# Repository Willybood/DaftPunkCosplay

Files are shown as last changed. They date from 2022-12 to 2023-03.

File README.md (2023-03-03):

# Daft Punk Cosplay
 A Daft Punk Cosplay created for London MCM ComicCon 2023. It consists of a set of LEDs and sound changer embedded into a helmet.
 The LED strip responds to the user talking, and the LED matrix plays animations when buttons embedded in a glove are pushed.
 
 <div align="center">
 
 
 
 
 </div>

 This design also features an 3D printed logo design which is then stitched onto the back and has threaded EL wire contained within.
 
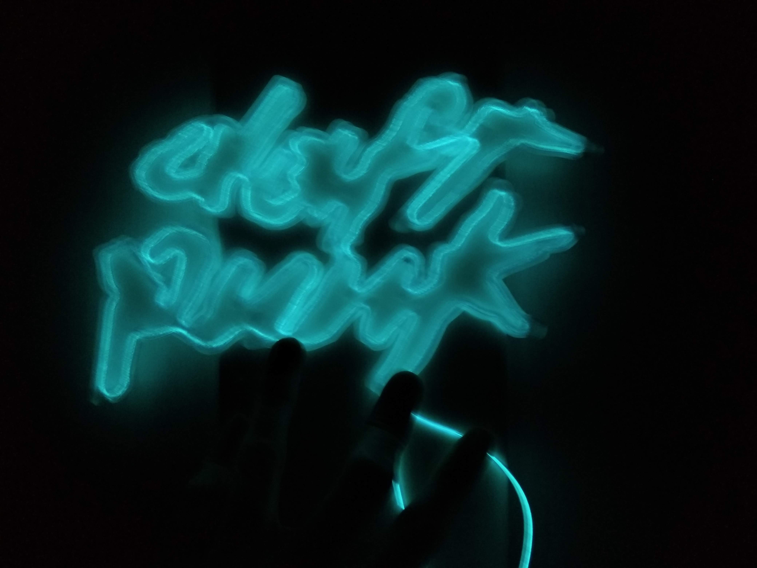
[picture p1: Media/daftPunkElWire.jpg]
 
 
 ## Bill of materials
  - [Raspberry Pi Zero W](https://www.amazon.co.uk/Raspberry-Pi-Zero-Wireless-model/dp/B06XFZC3BX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)
  - [WS2812B 8x8 LED matrix](https://www.amazon.co.uk/AZUOCN-Flexible-Individually-Addressable-Programmable/dp/B09DV8PZY1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)
  - [WS2812B LED strip, cut into 2 7 LED segments](https://www.amazon.co.uk/Individually-Addressable-Programmable-Waterproof-Decoration/dp/B0BLRN29V2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)
  - A USB sound card and adapter for the Pi
  - [A small lapel mic](https://www.amazon.co.uk/AGPTEK-Microphone-Professional-Omnidirectional-Condenser/dp/B07SHSHW6H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)
  - [A powered wired speaker](https://www.amazon.co.uk/dp/B07PDC69KT/ref=twister_B07PJNV454?_encoding=UTF8&psc=1)
  - 5 x little breadboard buttons
  - 2 x solderable breadboards
  - [Sound detector with digital output](https://www.amazon.co.uk/gp/product/B089QHMC8Y/ref=ppx_yo_dt_b_asin_title_o01_s00?ie=UTF8&psc=1)
  - 6 x 1.5 metre wires
  - 9 x 1.0 metre wires
  - 3 x 0.3 metre wires
  - A set of [Dupont cables](https://www.amazon.co.uk/gp/product/B07SYKPB86/ref=ppx_yo_dt_b_search_asin_title?ie=UTF8&psc=1)
  - A set of breadboard jumpers
  - One black suit, shirt, and tie
  - [A spaceman helmet](https://www.amazon.co.uk/gp/product/B01HQTGPIS/ref=ppx_yo_dt_b_search_asin_title?ie=UTF8&psc=1)
  - Modelling cardboard for the glove parts
  - Some black primer, gold, and clear finisher spraypaint to apply to the helmet and glove parts.
  - Natural 3D printer PLA
  - [Neon EL wire](https://www.amazon.co.uk/gp/product/B099FNFCY7/ref=ppx_yo_dt_b_search_asin_title?ie=UTF8&psc=1)
  - Some long thin black gloves
 ## Installation
On the Pi you can install the script by cloning the repository and running the command:
```
sudo python3 ./Install/install.py
```
The construction of the electronics can be seen in the Fritzing diagram:

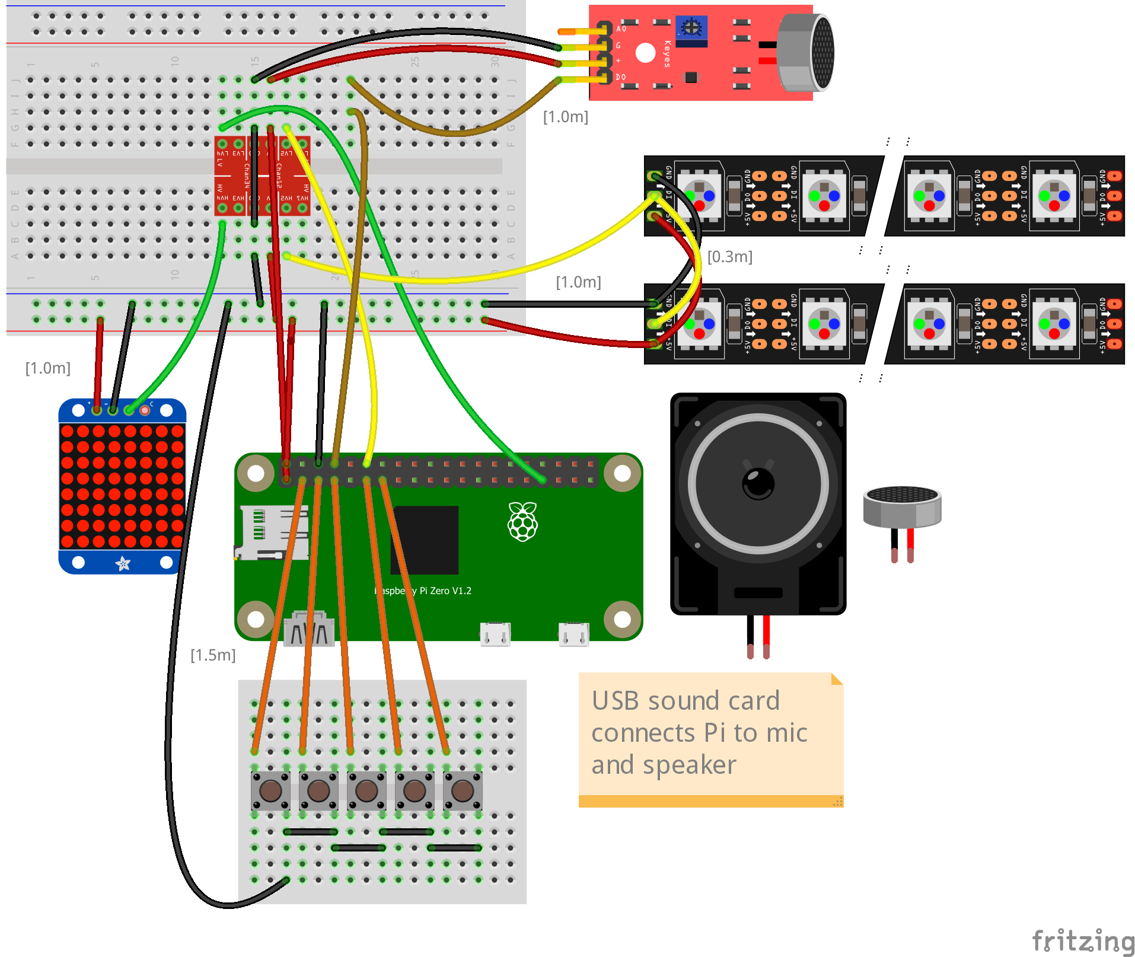
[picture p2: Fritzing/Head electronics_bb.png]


The lapel mic and sound detector were placed on the USB matrix in front of the mouth.
The gloves were made by cutting the modelling cardboard using a laser cutter and [the input SVG file](https://github.com/Willybood/DaftPunkCosplay/blob/main/Laser%20cuts/glove.svg).
The logo on the back was made using [this laser cut design](https://www.thingiverse.com/thing:683140) from Thingiverse (with special thanks to [Andyways](https://www.thingiverse.com/andyways)). It's available in the repo [here](https://github.com/Willybood/DaftPunkCosplay/blob/main/3D%20prints/DaftP_logo_mk1.1.stl) if needed.
## Running
Browse to the repo's folder and run the below command:
```
sudo python3 ./Python/main.py
```

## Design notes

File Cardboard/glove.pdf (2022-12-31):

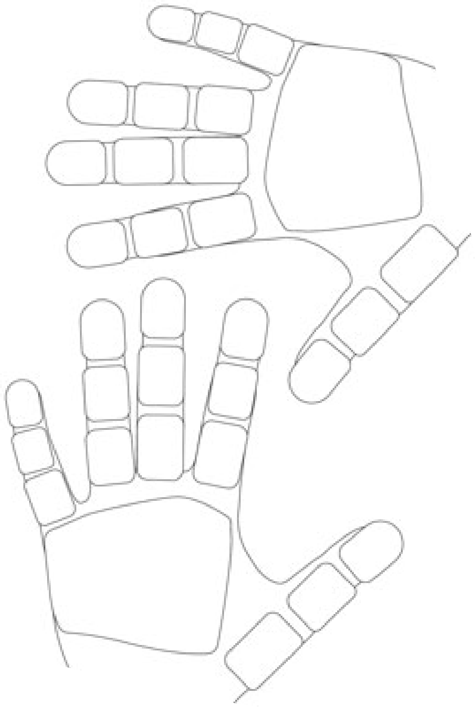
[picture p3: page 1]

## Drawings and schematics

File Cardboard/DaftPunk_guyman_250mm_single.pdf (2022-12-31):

up

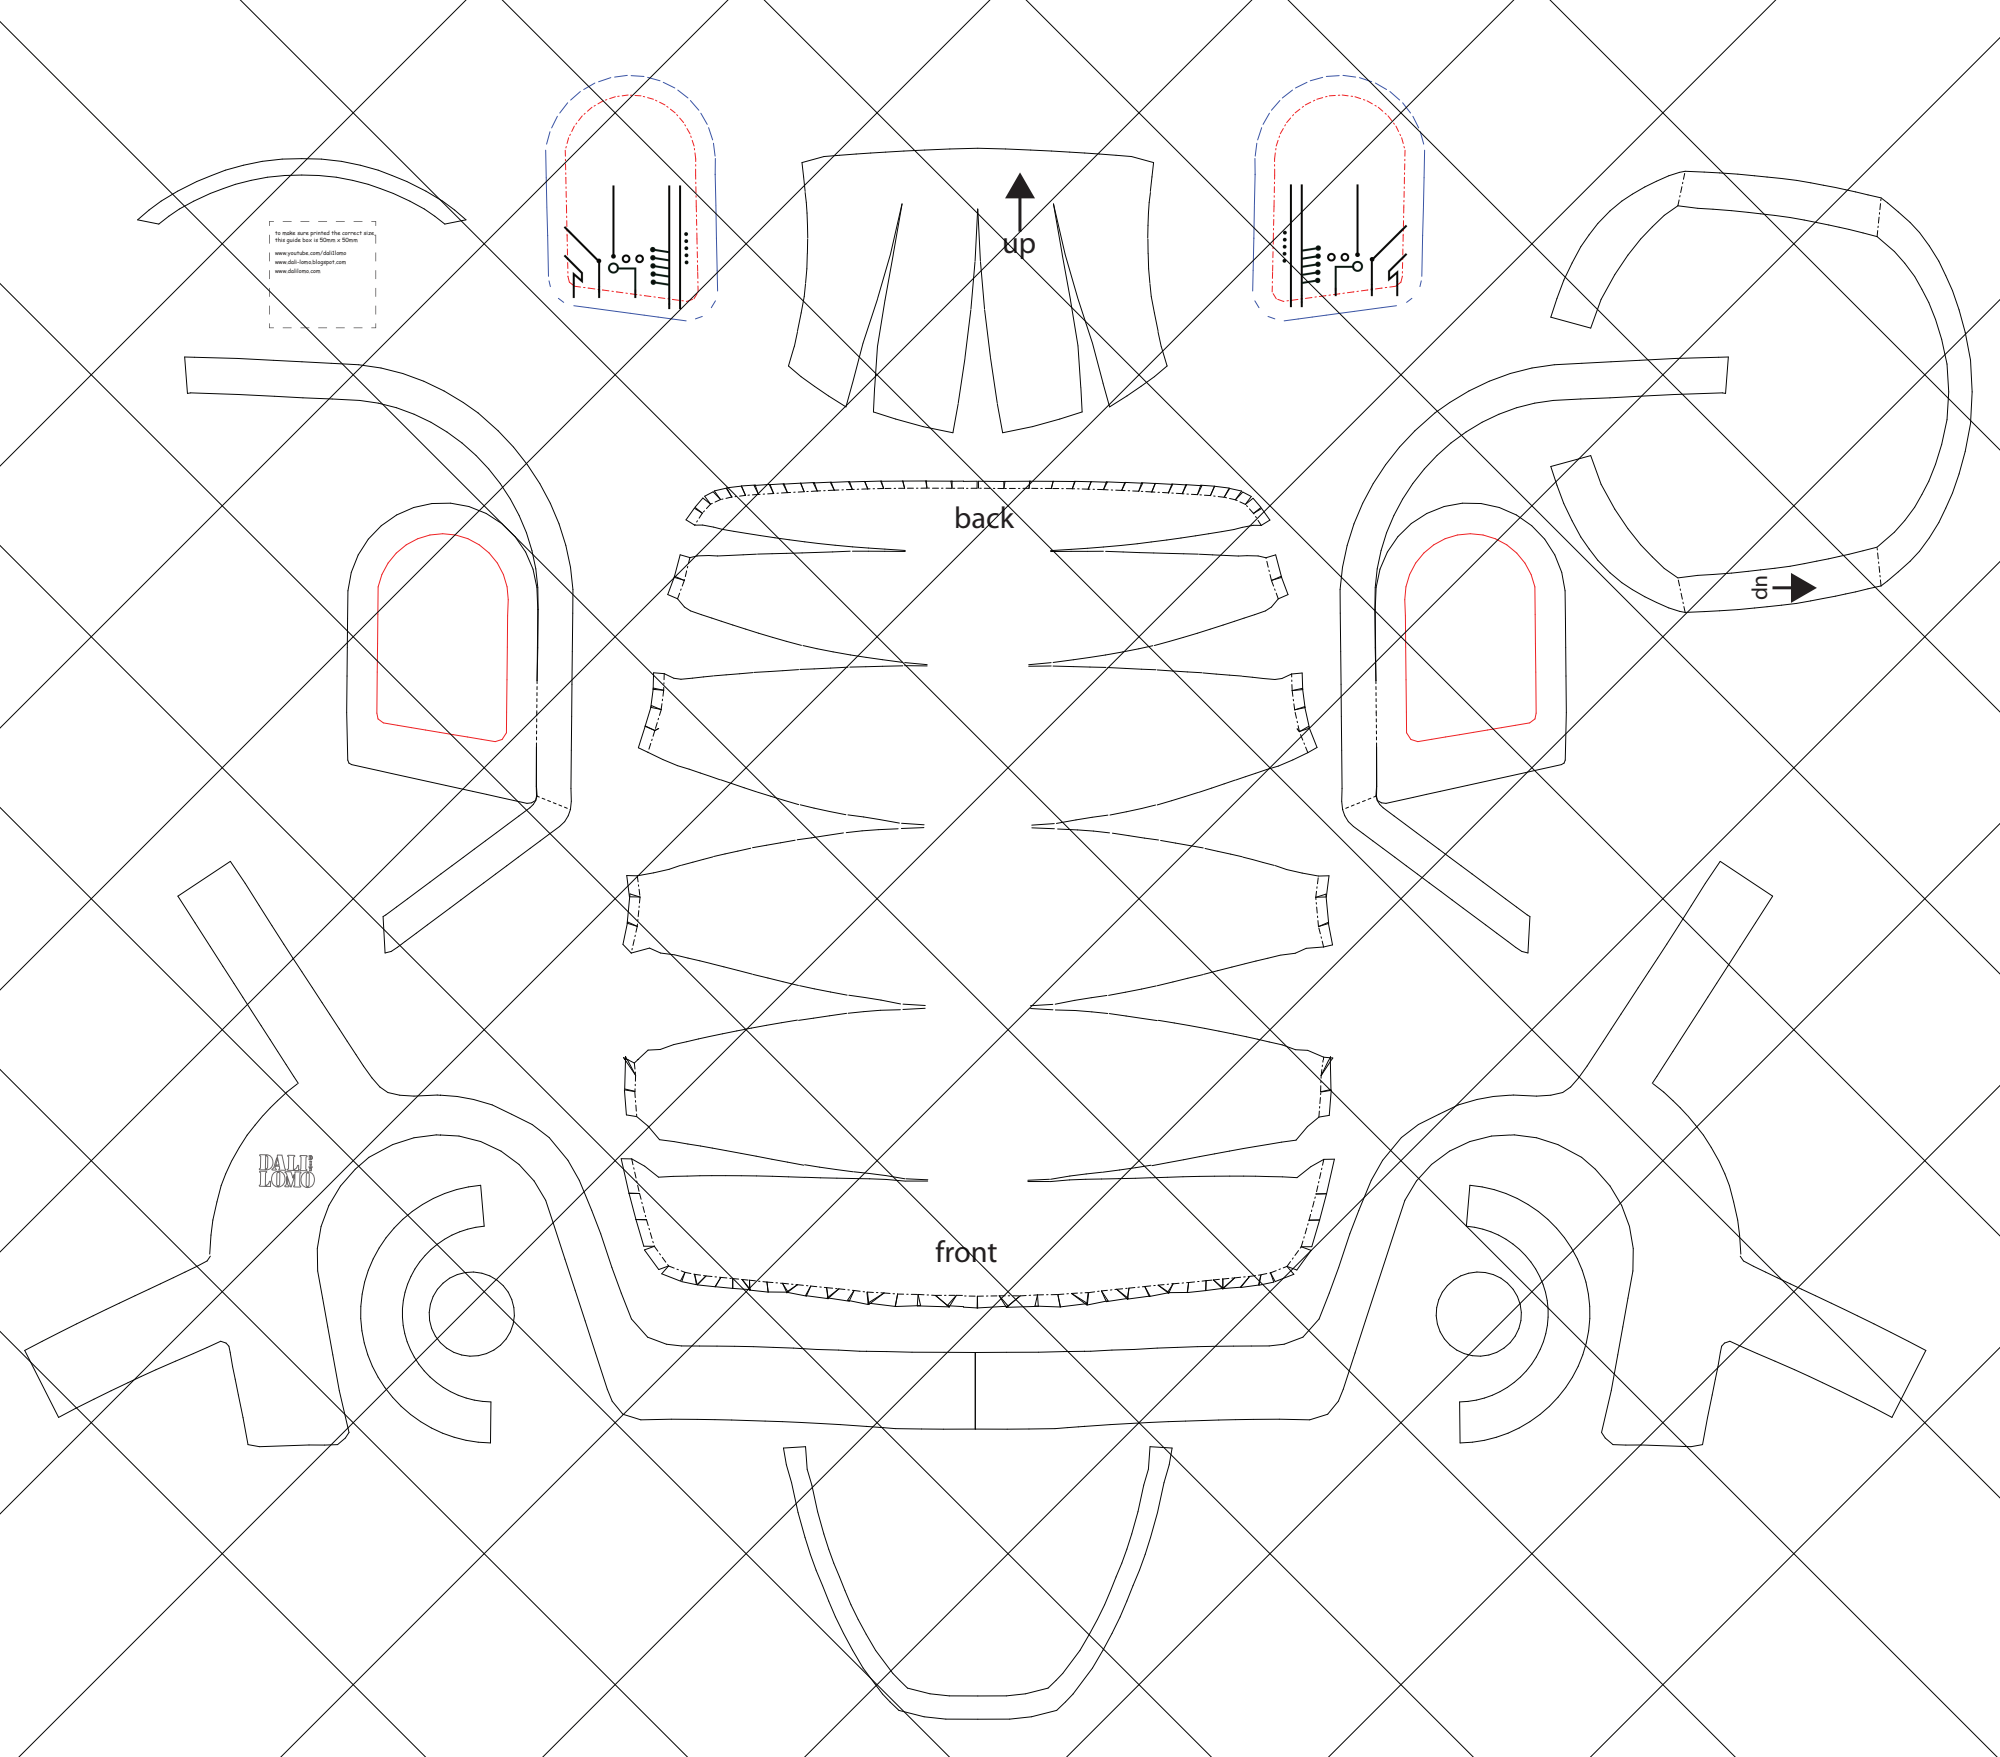
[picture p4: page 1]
back; front

to make sure printed the correct size,
this guide box is 50mm x 50mm
www.youtube.com/dali1lomo
www.dali-lomo.blogspot.com
www.dalilomo.com

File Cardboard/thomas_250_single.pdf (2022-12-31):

# dome

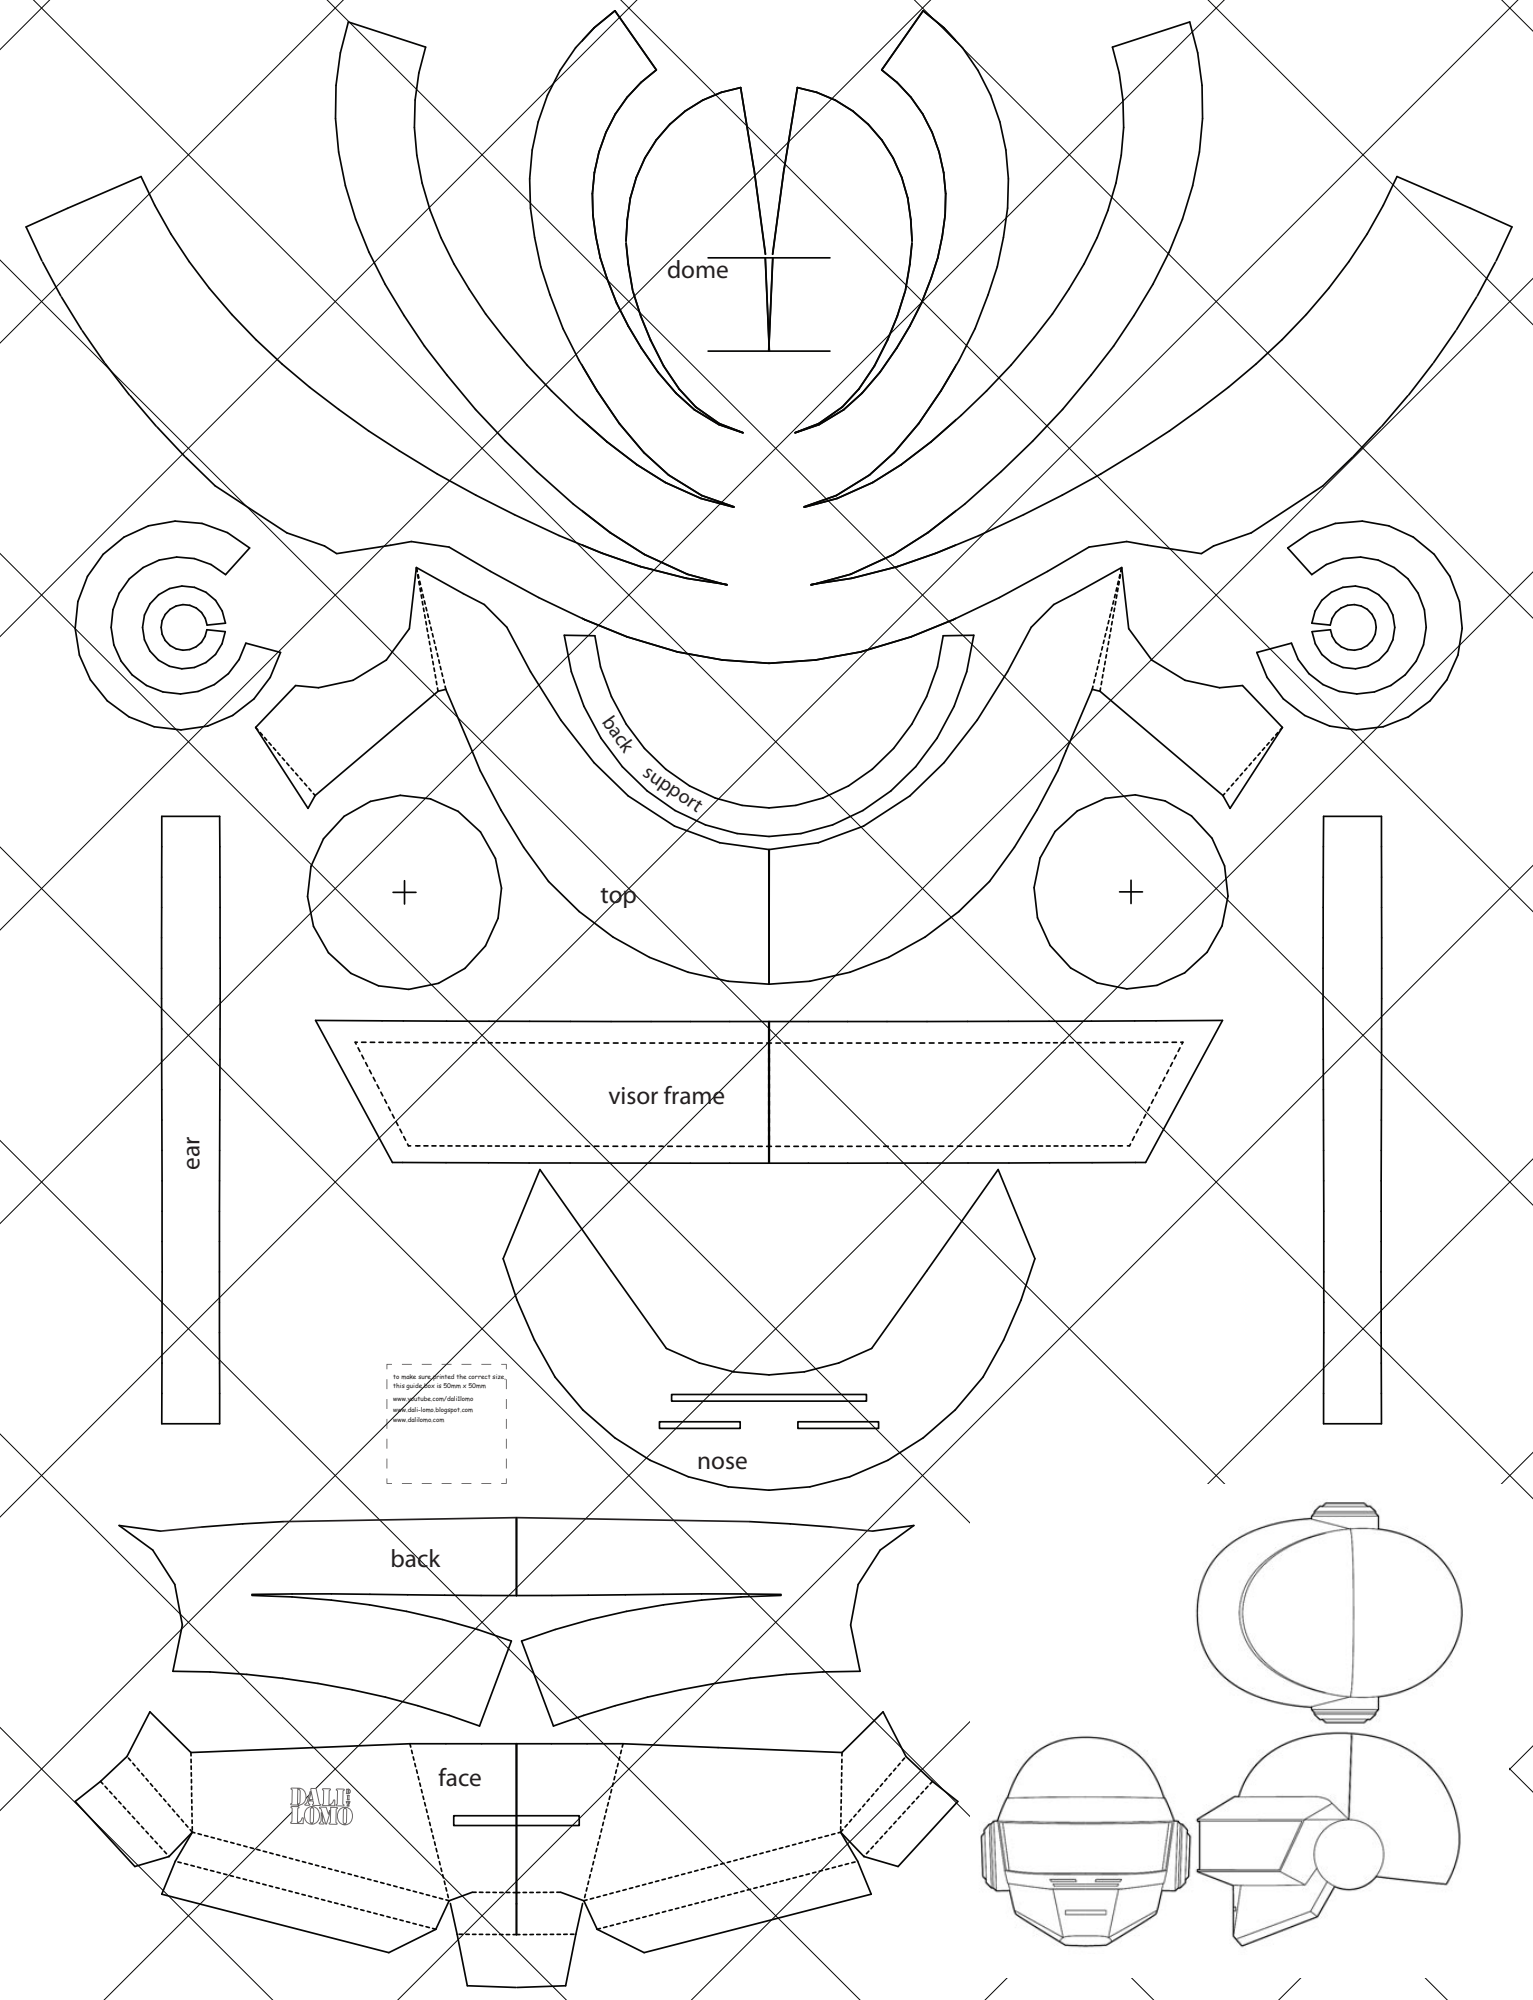
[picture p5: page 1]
top; back; face; nose; ear; visor frame; support

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

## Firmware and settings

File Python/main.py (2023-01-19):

# install.py
# Version: 1.0.0
# Contains main processing code required for DaftPunk cosplay
# Author: Billy Wood

import os
import animationPlayer
import threading
from mouthAnims import runMouthAnims
from audioMonitor import runAudioMonitor
from animationPlayer import playAnimation, clearMatrix

def runVoiceChanger():
    os.system("/usr/bin/play \"|rec --buffer 2096 -d synth sine fmod 5 echos 0.8 0.88 50 0.6\"")

def main():
    # Play animation on boot
    playAnimation("/home/pi/DaftPunkCosplay/pixelart animations/Hello.png", 100)
    clearMatrix()

    voiceChangerThread = threading.Thread(target=runVoiceChanger)
    voiceChangerThread.start()
    audioMonitorThread = threading.Thread(target = runAudioMonitor)
    audioMonitorThread.start()
    mouthAnimsThread = threading.Thread(target = runMouthAnims)
    mouthAnimsThread.start()

main()

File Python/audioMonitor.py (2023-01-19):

# audioMonitor.py
# Version: 1.0.0
# Contains audio monitoring and relevant LED output code
# Author: Billy Wood

import time
from rpi_ws281x import PixelStrip, Color
import RPi.GPIO as GPIO

# This function is run once and contains the loop that handles the audiomonitoring
def runAudioMonitor():
    audioDetectorPin = 14
    animPin = 18
    timeBetweenGpioChecks = 1 # ms
    timeBetweenLedChanges = 100 # ms
    ledCount = 7
    ledColours = [Color(255, 0, 0), Color(255, 128, 0), Color(255, 255, 0), Color(0, 255, 0), Color(0, 0, 255), Color(76, 0, 153), Color(127, 0, 255)]
    ledFreqHz = 800000   # LED signal frequency in hertz (usually 800khz)
    ledDma = 10          # DMA channel to use for generating signal (try 10)
    ledBrightness = 255  # Set to 0 for darkest and 255 for brightest
    ledInvert = False    # True to invert the signal (when using NPN transistor level shift)
    ledChannel = 0       # Is 0 for GPIO 18

    GPIO.setmode(GPIO.BCM)
    GPIO.setup(audioDetectorPin, GPIO.IN)

    strip = PixelStrip(ledCount, animPin, ledFreqHz, ledDma, ledInvert, ledBrightness, ledChannel)
    strip.begin()

    signalDetected = False
    currentActiveLed = 0
    secondsAtLastLedChange = time.time()
    while True:
        currentSeconds = time.time()
        secondsSinceLastLedChange = currentSeconds - secondsAtLastLedChange
        if(not signalDetected): # Only read the GPIO if signalDetected is false, that way positive reads have priority
            signalDetected = GPIO.input(audioDetectorPin)
        if(secondsSinceLastLedChange > (timeBetweenLedChanges / 1000.0)):
            if(signalDetected):
                if(currentActiveLed < ledCount):
                    currentActiveLed = currentActiveLed + 1
            else:
                if(currentActiveLed > 0):
                    currentActiveLed = currentActiveLed - 1

            for i in range (0, ledCount):
                if(i < currentActiveLed):
                    strip.setPixelColor(ledCount - (i + 1), ledColours[i])
                else:
                    strip.setPixelColor(ledCount - (i + 1), Color(0, 0, 0))
            strip.show()
            secondsAtLastLedChange = currentSeconds
            signalDetected = False
        time.sleep(timeBetweenGpioChecks / 1000.0)

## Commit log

2022-12-31 Initial commit with design files
    [Head electronics.fzz]
2023-01-01 Added glove lasercut
2023-01-02 Added hardware audio envelope detection
    [Head electronics.fzz]
2023-01-05 Added audio and button code
2023-01-07 Moved sound detection from envelope to gate
    [Head electronics.fzz]
2023-01-07 Schematic now includes level shifter
    [Head electronics.fzz]
2023-01-08 Added missing calls to main for new modules
    [main.py]
2023-01-08 Added led matrix code
2023-01-14 Corrected audio monitor following assembly
    [audioMonitor.py]
2023-01-14 Switched thread order Affected the LEDs for a reason I can't explain...
2023-01-14 Altered audio sensitivity and corrected output
    [Head electronics.fzz]
2023-01-14 Corrected issue affecting LED range
    [audioMonitor.py]
2023-01-15 Fixed local path error
    [main.py, mouthAnims.py]
2023-01-16 Switched to KY-038 audio sensor
    [Head electronics.fzz]
2023-01-18 Adjusted speed LEDs change
2023-01-18 Added delay between GPIO button checks
2023-01-19 Removed redundant power input
    [Head electronics.fzz]
2023-01-19 Switched audio monitor to 3.3v
    [Head electronics.fzz]
